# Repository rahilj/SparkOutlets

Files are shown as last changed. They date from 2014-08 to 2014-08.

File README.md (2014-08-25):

SparkOutlets
============

Spark controlled outlet switches
You'll need RF remote controlled outlet switches (http://www.amazon.com/dp/B00DQ2KGB2), optocouplers 
and Spark Core (spark.io) to control upto 5 outlets over the internet.
v_1 uses brute force hack
v_2 will be more elegant with a RF T emulating button press
More documentation on the project here:
https://community.spark.io/t/spark-controlled-outlet-switches/6283

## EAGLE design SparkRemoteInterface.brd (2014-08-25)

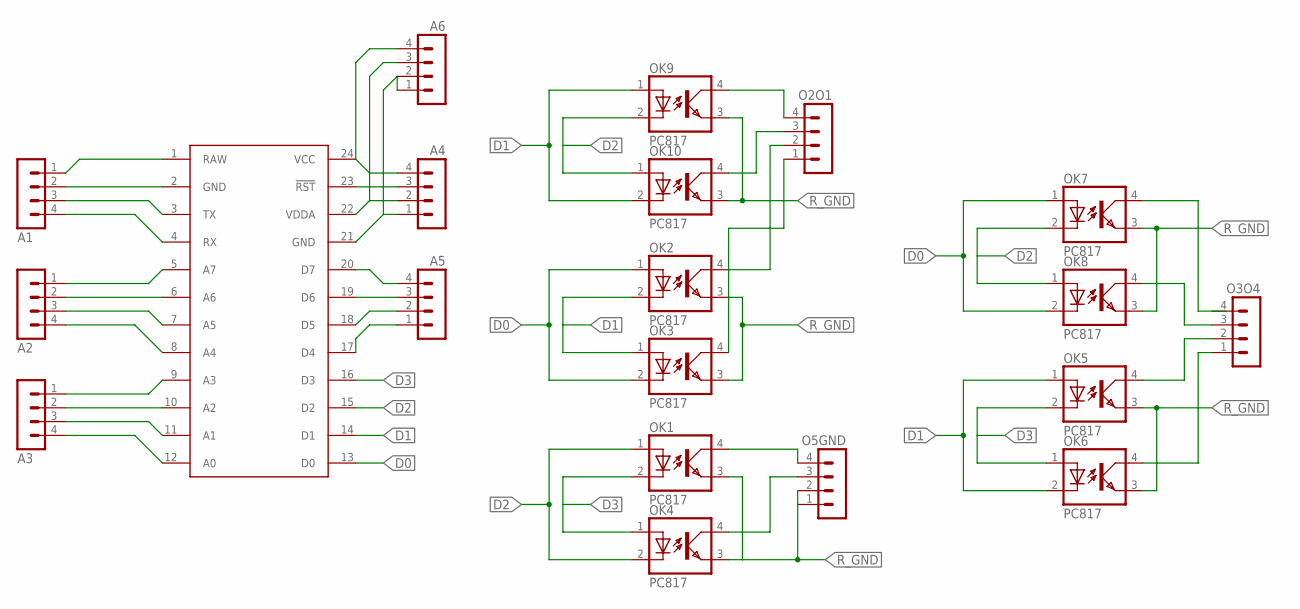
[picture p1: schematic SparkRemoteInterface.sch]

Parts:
A1, A2, A3, A4, A5, A6: MA04-1
O2O1, O3O4, O5GND: MA04-1
OK1, OK2, OK3, OK4, OK5, OK6, OK7, OK8, OK9, OK10: PC817; DIL04
U$1: SPARK_CORECORE; SPARK_CORE

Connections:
1R: O2O1.2, OK2.4 (COL)
1W: O2O1.1, OK3.4 (COL)
2R: O2O1.4, OK9.4 (COL)
2W: O2O1.3, OK10.4 (COL)
3R: OK7.4 (COL)
3W: O3O4.3, OK8.4 (COL)
4R: O3O4.2, OK5.4 (COL)
4W: O3O4.1, OK6.4 (COL)
5R: O5GND.4, OK1.4 (COL)
5W: O5GND.3, OK4.4 (COL)
D0: OK2.1 (A), OK3.2 (C), OK7.1 (A), OK8.2 (C), U$1.13 (D0)
D1: OK2.2 (C), OK3.1 (A), OK5.1 (A), OK6.2 (C), OK9.1 (A), OK10.2 (C), U$1.14 (D1)
D2: OK1.1 (A), OK4.2 (C), OK7.2 (C), OK8.1 (A), OK9.2 (C), OK10.1 (A), U$1.15 (D2)
D3: OK1.2 (C), OK4.1 (A), OK5.2 (C), OK6.1 (A), U$1.16 (D3)
unnamed: A1.1, U$1.1 (RAW)
unnamed: A3.1, U$1.9 (A3)
unnamed: A1.2, U$1.2 (GND)
unnamed: A1.3, U$1.3 (TX)
unnamed: A1.4, U$1.4 (RX)
unnamed: A2.1, U$1.5 (A7)
unnamed: A2.2, U$1.6 (A6)
unnamed: A2.3, U$1.7 (A5)
unnamed: A2.4, U$1.8 (A4)
unnamed: A3.2, U$1.10 (A2)
unnamed: A3.3, U$1.11 (A1)
unnamed: A3.4, U$1.12 (A0)
unnamed: A4.4, A6.4, U$1.24 (VCC)
unnamed: A4.3, U$1.23 (!RST)
unnamed: A4.2, A6.3, U$1.22 (VDDA)
unnamed: A4.1, A6.1, A6.2, U$1.21 (GND)
unnamed: A5.4, U$1.20 (D7)
unnamed: A5.3, U$1.19 (D6)
unnamed: A5.2, U$1.18 (D5)
unnamed: A5.1, U$1.17 (D4)
R_GND: O5GND.1, O5GND.2, OK1.3 (EMIT), OK2.3 (EMIT), OK3.3 (EMIT), OK4.3 (EMIT), OK5.3 (EMIT), OK6.3 (EMIT), OK7.3 (EMIT), OK8.3 (EMIT), OK9.3 (EMIT), OK10.3 (EMIT)

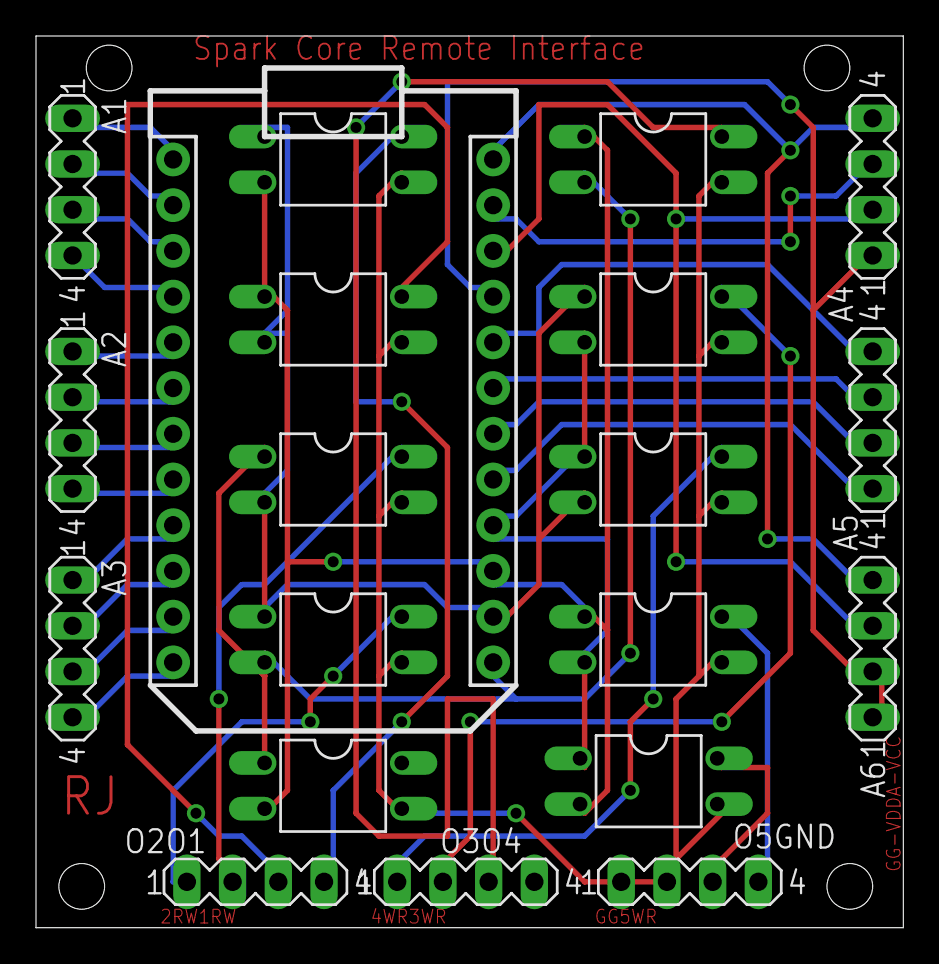
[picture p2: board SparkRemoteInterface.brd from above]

Board: 2 copper layers, 48.2 x 49.5 mm, 20 parts (0 on the bottom side), 34 nets.

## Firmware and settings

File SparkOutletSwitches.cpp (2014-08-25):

//Spark controlled outlet switches ver1.0
//Initialize
#define ON 1
#define OFF 0


int Outlet1State = 0;
int Outlet2State = 0;
int Outlet3State = 0;
int Outlet4State = 0;
int Outlet5State = 0;

//Pin descriptions - see schematic
//Outlet 1 D0 HIGH D1 LOW - ON
//		 D0 LOW D1 HIGH - OFF

//Outlet 2 D1 HIGH D2 LOW - ON
//		 D1 LOW D2 HIGH - OFF
		 
//Outlet 3 D2 HIGH D3 LOW - ON
//		 D2 LOW D3 HIGH - OFF

//Outlet 4 D0 HIGH D2 LOW - ON
//		 D0 LOW D2 HIGH - OFF

//Outlet 5 D1 HIGH D3 LOW - ON
//		 D1 LOW D3 HIGH - OFF
int O1_PINS[] = {D0,D1};
int O2_PINS[] = {D1,D2};
int O3_PINS[] = {D2,D3};
int O4_PINS[] = {D0,D2};
int O5_PINS[] = {D1,D3};

uint32_t UPDATE_INTERVAL = 10; // in milliseconds
uint32_t FIFTEEN_MINUTES = 60*15*1000; // in milliseconds

uint32_t lastTime = 0; // in milliseconds
uint32_t startTime = 0; // in milliseconds

void setup() {
	//Initialize all input as ionputs for tristating unless switched
    pinMode(O1_PINS[0],INPUT); 
    pinMode(O1_PINS[1],INPUT);
    pinMode(O2_PINS[1],INPUT);
    pinMode(O3_PINS[1],INPUT);

    digitalWrite(O1_PINS[0],LOW);
    digitalWrite(O1_PINS[1],LOW);
    digitalWrite(O2_PINS[1],LOW);
    digitalWrite(O3_PINS[1],LOW);
    
    Spark.function("out1", outlet5);
    Spark.function("out2", outlet1);
    Spark.function("out3", outlet2);
    Spark.function("out4", outlet3);
    Spark.function("out5", outlet4);
	
    Spark.variable("Outlet1State", &Outlet1State, INT);
    Spark.variable("Outlet2State", &Outlet2State, INT);
    Spark.variable("Outlet3State", &Outlet3State, INT);
	Spark.variable("Outlet4State", &Outlet4State, INT);
    Spark.variable("Outlet5State", &Outlet5State, INT);
}

void loop() {
    // Update the filter every 10ms (default)
    if(millis() - lastTime > UPDATE_INTERVAL) {
        // Set a new last time
        lastTime = millis();
   
    }
}

int outlet1(String args) {
    if(Outlet1State == OFF) {
		//Do thrice just to be sure
        for (int i = 0; i < 2; i = i + 1) {
		    pinMode(O1_PINS[0],OUTPUT); 
			pinMode(O1_PINS[1],OUTPUT);
			digitalWrite(O1_PINS[0], LOW); // Assert low on both pins
			digitalWrite(O1_PINS[1], LOW);
			delay(500);
			digitalWrite(O1_PINS[0], HIGH); //Action
			delay(500);
			digitalWrite(O1_PINS[0], LOW); //Go low again
			delay(500);
		}
		//Tristate output by setting back as input
		pinMode(O1_PINS[0],INPUT); 
		pinMode(O1_PINS[1],INPUT);
		Outlet1State = ON; // Outlet 1 started
        return 200; // This is checked in the web app controller for validation
    }
    else {
		//Do thrice just to be sure
        for (int i = 0; i < 2; i = i + 1) {
		    pinMode(O1_PINS[0],OUTPUT); 
			pinMode(O1_PINS[1],OUTPUT);
			digitalWrite(O1_PINS[0], LOW); // Assert low on both pins
			digitalWrite(O1_PINS[1], LOW);
			delay(500);
			digitalWrite(O1_PINS[1], HIGH); //Action
			delay(500);
			digitalWrite(O1_PINS[1], LOW); //Go low again
			delay(500);
		}
		//Tristate output by setting as input
		pinMode(O1_PINS[0],INPUT); 
		pinMode(O1_PINS[1],INPUT);
        Outlet1State = OFF; //Outlet 1 stopped
        return 200; // This is checked in the web app controller for validation
    }
}

int outlet2(String args) {
    if(Outlet2State == OFF) {
		//Do thrice just to be sure
        for (int i = 0; i < 2; i = i + 1) {
		    pinMode(O2_PINS[0],OUTPUT); 
			pinMode(O2_PINS[1],OUTPUT);
			digitalWrite(O2_PINS[0], LOW); // Assert low on both pins
			digitalWrite(O2_PINS[1], LOW);
			delay(500);
			digitalWrite(O2_PINS[0], HIGH); //Action
			delay(500);
			digitalWrite(O2_PINS[0], LOW); //Go low again
			delay(500);
		}
		//Tristate output by setting back as input
		pinMode(O2_PINS[0],INPUT); 
		pinMode(O2_PINS[1],INPUT);
		Outlet2State = ON; // Outlet 2 started
        return 200; // This is checked in the web app controller for validation
    }
    else {
		//Do thrice just to be sure
        for (int i = 0; i < 2; i = i + 1) {
		    pinMode(O2_PINS[0],OUTPUT); 
			pinMode(O2_PINS[1],OUTPUT);
			digitalWrite(O2_PINS[0], LOW); // Assert low on both pins
			digitalWrite(O2_PINS[1], LOW);
			delay(500);
			digitalWrite(O2_PINS[1], HIGH); //Action
			delay(500);
			digitalWrite(O2_PINS[1], LOW); //Go low again
			delay(500);
		}
		//Tristate output by setting as input
		pinMode(O2_PINS[0],INPUT); 
		pinMode(O2_PINS[1],INPUT);
        Outlet2State = OFF; // Outlet 2 stopped
        return 200; // This is checked in the web app controller for validation
    }
}

int outlet3(String args) {
    if(Outlet3State == OFF) {
		//Do thrice just to be sure
        for (int i = 0; i < 2; i = i + 1) {
		    pinMode(O3_PINS[0],OUTPUT); 
			pinMode(O3_PINS[1],OUTPUT);
			digitalWrite(O3_PINS[0], LOW); // Assert low on both pins
			digitalWrite(O3_PINS[1], LOW);
			delay(500);
			digitalWrite(O3_PINS[0], HIGH); //Action
			delay(500);
			digitalWrite(O3_PINS[0], LOW); //Go low again
			delay(500);
		}
		//Tristate output by setting back as input
		pinMode(O3_PINS[0],INPUT); 
		pinMode(O3_PINS[1],INPUT);
		Outlet3State = ON; // Outlet 3 started
        return 200; // This is checked in the web app controller for validation
    }
    else {
		//Do thrice just to be sure
        for (int i = 0; i < 2; i = i + 1) {
		    pinMode(O3_PINS[0],OUTPUT); 
			pinMode(O3_PINS[1],OUTPUT);
			digitalWrite(O3_PINS[0], LOW); // Assert low on both pins
			digitalWrite(O3_PINS[1], LOW);
			delay(500);
			digitalWrite(O3_PINS[1], HIGH); //Action
			delay(500);
			digitalWrite(O3_PINS[1], LOW); //Go low again
			delay(500);
		}
		//Tristate output by setting as input
		pinMode(O3_PINS[0],INPUT); 
		pinMode(O3_PINS[1],INPUT);
        Outlet3State = OFF; // Outlet 3 stopped
        return 200; // This is checked in the web app controller for validation
    }
}


int outlet4(String args) {
    if(Outlet4State == OFF) {
		//Do thrice just to be sure
        for (int i = 0; i < 2; i = i + 1) {
		    pinMode(O4_PINS[0],OUTPUT); 
			pinMode(O4_PINS[1],OUTPUT);
			digitalWrite(O4_PINS[0], LOW); // Assert low on both pins
			digitalWrite(O4_PINS[1], LOW);
			delay(500);
			digitalWrite(O4_PINS[0], HIGH); //Action
			delay(500);
			digitalWrite(O4_PINS[0], LOW); //Go low again
			delay(500);
		}
		//Tristate output by setting back as input
		pinMode(O4_PINS[0],INPUT); 
		pinMode(O4_PINS[1],INPUT);
		Outlet4State = ON; // Outlet 4 started
        return 200; // This is checked in the web app controller for validation
    }
    else {
		//Do thrice just to be sure
        for (int i = 0; i < 2; i = i + 1) {
		    pinMode(O4_PINS[0],OUTPUT); 
			pinMode(O4_PINS[1],OUTPUT);
			digitalWrite(O4_PINS[0], LOW); // Assert low on both pins
			digitalWrite(O4_PINS[1], LOW);
			delay(500);
			digitalWrite(O4_PINS[1], HIGH); //Action
			delay(500);
			digitalWrite(O4_PINS[1], LOW); //Go low again
			delay(500);
		}
		//Tristate output by setting as input
		pinMode(O4_PINS[0],INPUT); 
		pinMode(O4_PINS[1],INPUT);
        Outlet4State = OFF; // Outlet 4 stopped
        return 200; // This is checked in the web app controller for validation
    }
}

int outlet5(String args) {
    if(Outlet5State == OFF) {
		//Do thrice just to be sure
        for (int i = 0; i < 2; i = i + 1) {
		    pinMode(O5_PINS[0],OUTPUT); 
			pinMode(O5_PINS[1],OUTPUT);
			digitalWrite(O5_PINS[0], LOW); // Assert low on both pins
			digitalWrite(O5_PINS[1], LOW);
			delay(500);
			digitalWrite(O5_PINS[0], HIGH); //Action
			delay(500);
			digitalWrite(O5_PINS[0], LOW); //Go low again
			delay(500);
		}
		//Tristate output by setting back as input
		pinMode(O5_PINS[0],INPUT); 
		pinMode(O5_PINS[1],INPUT);
		Outlet5State = ON; // Outlet 5 started
        return 200; // This is checked in the web app controller for validation
    }
    else {
		//Do thrice just to be sure
        for (int i = 0; i < 2; i = i + 1) {
		    pinMode(O5_PINS[0],OUTPUT); 
			pinMode(O5_PINS[1],OUTPUT);
			digitalWrite(O5_PINS[0], LOW); // Assert low on both pins
			digitalWrite(O5_PINS[1], LOW);
			delay(500);
			digitalWrite(O5_PINS[1], HIGH); //Action
			delay(500);
			digitalWrite(O5_PINS[1], LOW); //Go low again
			delay(500);
		}
		//Tristate output by setting as input
		pinMode(O5_PINS[0],INPUT); 
		pinMode(O5_PINS[1],INPUT);
        Outlet5State = OFF; // Outlet 5 stopped
        return 200; // This is checked in the web app controller for validation
    }
}

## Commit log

2014-08-25 Create SparkRemoteInterface.brd
    Connection missing - 3R and OK8 or OK7
    [SparkRemoteInterface.brd]
2014-08-25 Create SparkRemoteInterface.sch
    Schematic for Spark core and Remote interface
    [SparkRemoteInterface.sch]
